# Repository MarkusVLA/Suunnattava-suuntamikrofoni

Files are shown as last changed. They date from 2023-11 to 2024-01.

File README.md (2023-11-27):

# Suunnattava suuntamikrofoni 

Suunnattava suuntamikrofoni on laite, jolla voidaan elektronisesti ohjata äänityksen suuntaa käännettävän suuntauksen avulla. Laite koostuu kahdesta piirikortista: Ensimmäinen piirikortti sisältää kuuden mikrofonin ryhmän, josta luetaan dataa. Toinen piirikortti hoitaa signaalinkäsittelyn ja laitteen ohjauksen ESP32-S3-mikro-ohjaimeen perustuvalla järjestelmällä.

## Mikrofonipiiri

-   ...

## Signaalinkäsittelypiiri

<p float="left">
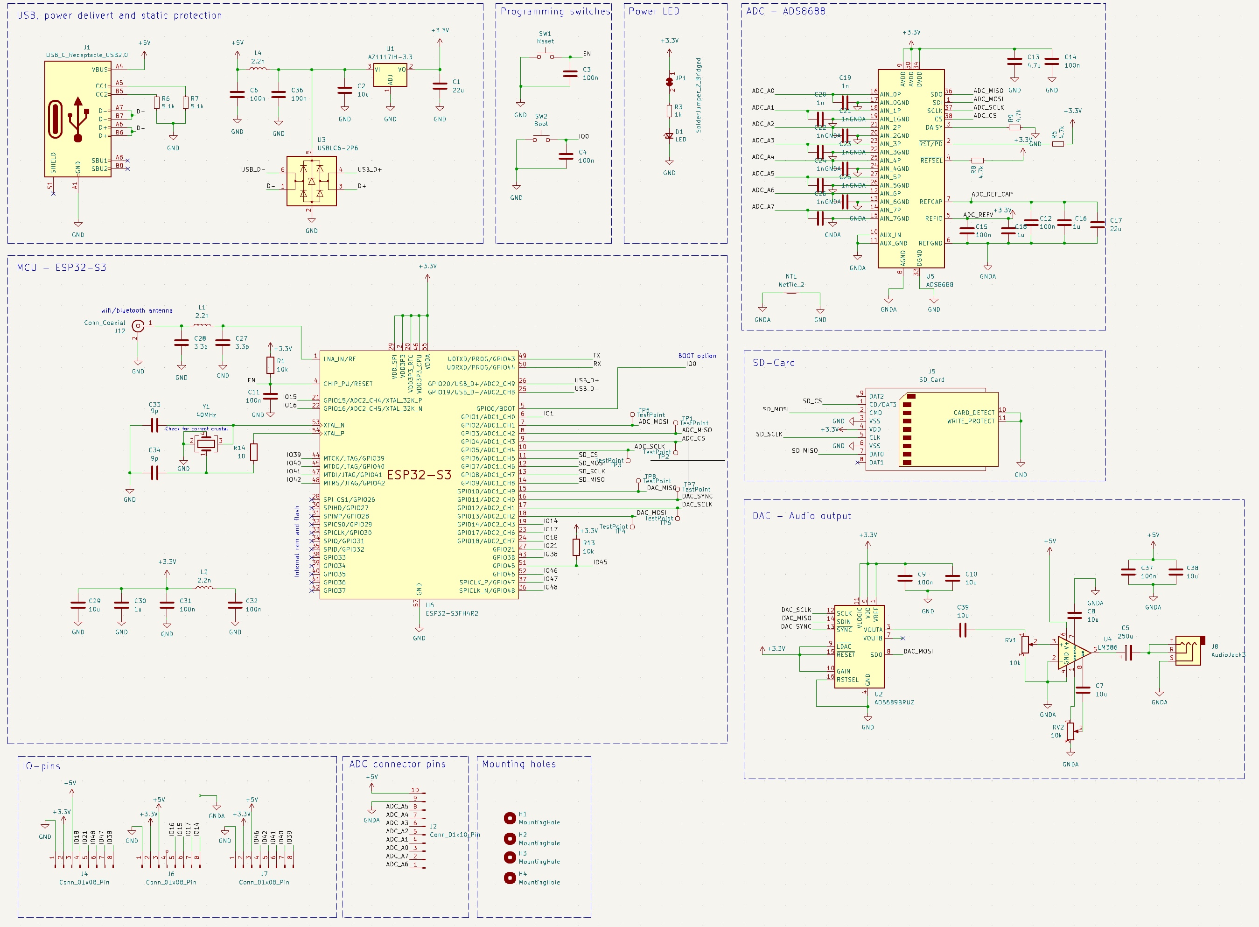
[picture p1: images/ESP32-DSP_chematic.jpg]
  
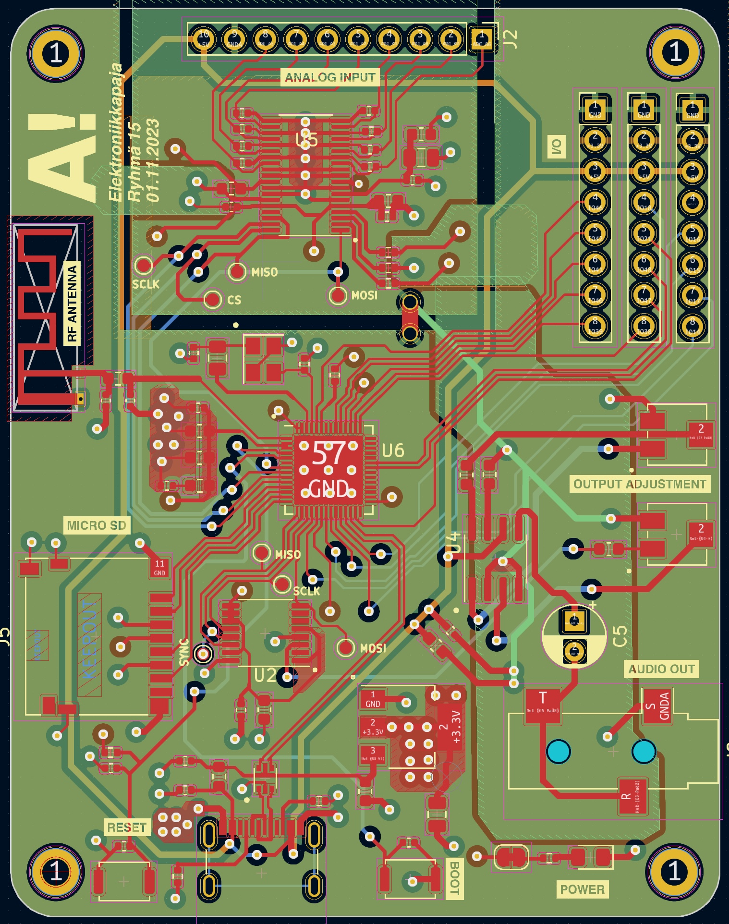
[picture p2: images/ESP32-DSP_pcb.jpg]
  
  <p>Kuva 1: ESP32-DSP piirikaavio ja piirikortti</p>
</p>

<p float="left">
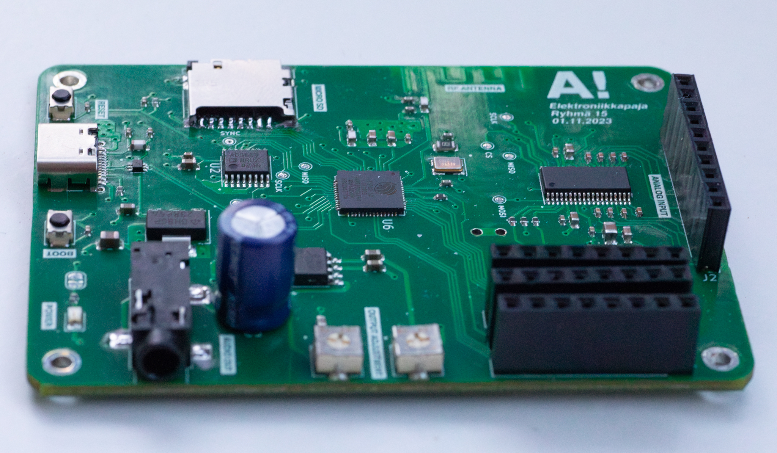
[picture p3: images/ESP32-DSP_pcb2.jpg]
  
  <p>Kuva 2: ESP32-DSP piirikortti toteutettuna</p>
</p>

## TODO
* [x] DSP alustan suunnittelu
* [x] Mikrofoonipiirin suunnittelu
* [x] Piirikorttien kasaus
* [x] Datan keräys ADS8688-ADC:n avulla
* [ ] Beam forming algoritmi
* [ ] Äänen toisto käyttäjälle

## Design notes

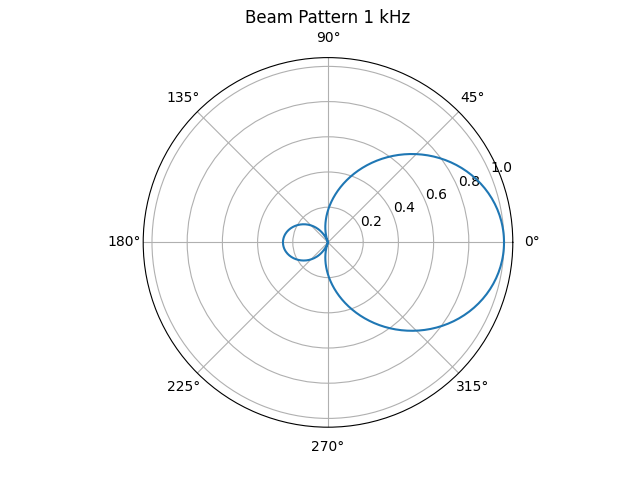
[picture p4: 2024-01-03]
images/Beam_pattern_1kHz.png

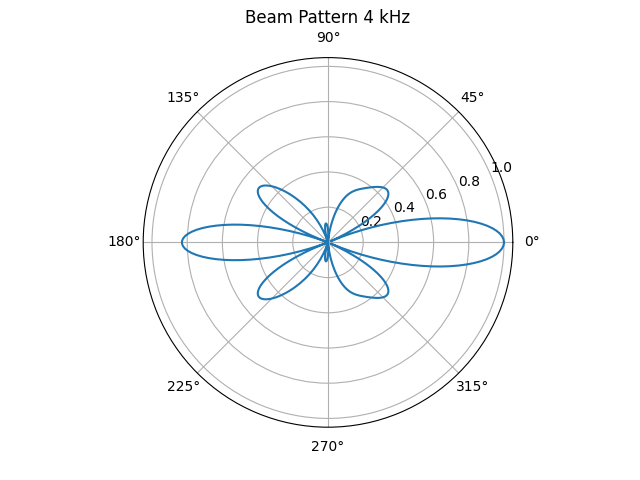
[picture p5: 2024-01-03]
images/Beam_pattern_4kHz.png

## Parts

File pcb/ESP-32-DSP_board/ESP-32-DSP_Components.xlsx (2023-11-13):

Designator | Footprint | Quantity | Value | Component cost [€] | Order link
C10, C2, C29, C38, C39, C7, C8 | 603 | 7 | 10u | 0.12 € | https://www.digikey.fi/fi/products/detail/murata-electronics/GRM188R61A106ME69D/5027560
C11, C12, C14, C15, C3, C31, C32, C36, C4, C6, C37, C9 | 402 | 12 | 100n | 0.09 € | https://www.digikey.fi/fi/products/detail/samsung-electro-mechanics/CL05A104KA5NNNC/3886701
C13 | 603 | 1 | 4.7u | 0.09 € | https://www.digikey.fi/fi/products/detail/samsung-electro-mechanics/CL10A475KP8NNNC/3886702
C16, C18, C30 | 603 | 3 | 1u | 0.09 € | https://www.digikey.fi/fi/products/detail/samsung-electro-mechanics/CL10A105KA8NNNC/3886760
C17 | 805 | 2 | 22u | 0.12 € | https://www.digikey.fi/fi/products/detail/kemet/C0805C224K5RAC7800/754753
C19, C20, C21, C22, C23, C24, C25, C26 | 402 | 8 | 1n | 0.18 € | https://www.digikey.fi/fi/products/detail/tdk-corporation/C1005C0G1H102J050BE/11697944
C27, C28 | 402 | 2 | 3.3p | 0.24 € | https://www.digikey.fi/fi/products/detail/johanson-technology-inc/QSCF500Q3R3B1GV001T/1561531
C33, C34 | 402 | 2 | 20p (crystal load capacitance) | 0.14 € | https://www.digikey.fi/fi/products/detail/murata-electronics/GJM1555C1H200FB01D/2592908
D1 | 805 | 1 | LED | 0.24 € | https://www.digikey.fi/fi/products/detail/liteon/LTST-C171GKT/386793
J1 | USB_C_Receptacle_G-Switch_GT-USB-7010ASV | 1 | USB_C_Receptacle_USB2.0 | 0.94 € | https://www.digikey.fi/fi/products/detail/amphenol-cs-commercial-products/12402012E212A/13683192
J5 | microSD_HC_Hirose_DM3D-SF | 1 | SD_Card | 1.66 € | https://www.digikey.fi/fi/products/detail/hirose-electric-co-ltd/DM3D-SF/1786510
J8 | Jack_3.5mm_Switronic_ST-005-G_horizontal | 1 | AudioJack3 | 1.50 € | https://www.digikey.fi/fi/products/detail/kycon-inc/STX-3500-3NTR/9975996
L1, L2, L4 | 603 | 3 | 2.2n | 0.09 € | https://www.digikey.fi/fi/products/detail/johanson-technology-inc/LRC0603CS2N2GV001T/1561288
R1, R13 | 402 | 2 | 10k | 0.09 € | https://www.digikey.fi/fi/products/detail/bourns-inc/CR0402-FX-1002GLF/3593192
R14 | 805 | 1 | 10 | 0.10 € | https://www.digikey.fi/fi/products/detail/panasonic-electronic-components/ERJ-6ENF10R0V/110893
R3 | 402 | 1 | 1k | 0.09 € | https://www.digikey.fi/fi/products/detail/yageo/RC0402FR-071KL/726513
R5, R8, R9 | 402 | 3 | 4.7k | 0.09 € | https://www.digikey.fi/fi/products/detail/yageo/RC0402FR-074K7L/2827563
R6, R7 | 402 | 2 | 5.1k | 0.09 € | https://www.digikey.fi/fi/products/detail/yageo/RC0402FR-135K1L/14286364
RV1, RV2 | Potentiometer_Bourns_3214J_Horizontal | 2 | 10k | 1.73 € | https://www.digikey.fi/fi/products/detail/bourns-inc/3314J-1-103E/86580
SW1 | SW_Push_SPST_NO_Alps_SKRK | 1 | Reset | 0.72 € | https://www.digikey.fi/fi/products/detail/alps-alpine/SKRKAHE020/19529210
SW2 | SW_Push_SPST_NO_Alps_SKRK | 1 | Boot | 0.72 € | https://www.digikey.fi/fi/products/detail/alps-alpine/SKRKAHE020/19529210
U1 | SOT-223-3_TabPin2 | 1 | AZ1117IH-3.3 | 0.36 € | https://www.digikey.fi/fi/products/detail/diodes-incorporated/AZ1117IH-3-3TRG1/5699672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
U2 | TSSOP-16_4.4x5mm_P0.65mm | 1 | AD5689BRUZ | 10.66 € | https://www.digikey.fi/fi/products/detail/analog-devices-inc/AD5689BRUZ/3925735
U3 | SOT-666 | 1 | USBLC6-2P6 | 0.59 € | https://www.digikey.fi/fi/products/detail/stmicroelectronics/USBLC6-2P6/1007440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
U4 | SOIC-8_3.9x4.9mm_P1.27mm | 1 | LM386 | 1.05 € | https://www.digikey.fi/fi/products/detail/texas-instruments/LM386MX-1-NOPB/212680
U5 | TSSOP-38_4.4x9.7mm_P0.5mm | 1 | ADS8688 | 19.29 € | https://www.digikey.fi/fi/products/detail/texas-instruments/ADS8688AIDBT/5417855
U6 | QFN-56-1EP_7x7mm_P0.4mm_EP5.6x5.6mm | 1 | ESP32-S3FH4R2 | 2.16 € | https://www.mouser.fi/ProductDetail/Espressif-Systems/ESP32-S3FH4R2?qs=tlsG%2FOw5FFjPrwkmZSBQNA%3D%3D
Y1 | Crystal_SMD_3225-4Pin_3.2x2.5mm | 1 | 40MHz | 0.40 € | https://www.digikey.fi/fi/products/detail/ecs-inc/ECS-400-18-33-JGN-TR3/14825140
Board cost [€]:
49.56

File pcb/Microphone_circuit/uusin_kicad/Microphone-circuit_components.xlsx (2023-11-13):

Designator | Footprint | Quantity | Value | Component cost [€] | Order link
C1, C11, C16, C21, C26, C6 | 805 | 8 | 0.1u | 0.09 € | https://www.digikey.fi/fi/products/detail/kemet/C0805C104M5RAC7800/411168
C10, C15, C2, C20, C25, C30 | CP_Radial_D7.5mm_P2.50mm |  | 100u | 0.00 € | Pajalta
C12, C13, C17, C18, C22, C23, C27, C28, C3, C4, C7, C8 | 805 | 14 | 10u | 0.15 € | https://www.digikey.fi/fi/products/detail/murata-electronics/GRM21BR61C106KE15K/2546903
C14, C19, C24, C29, C5, C9 | 805 | 8 | 0.047u | 0.13 € | https://www.digikey.fi/fi/products/detail/kemet/C0805C473K5RAC7800/411165
C31, C32, C33, C34, C35, C36 | 805 | 8 | 5n | 0.24 € | https://www.digikey.fi/fi/products/detail/kyocera-avx/08055C502KAT2A/1603019
MK1, MK2, MK3, MK4, MK5, MK6 | Mikrophoni1 | 8 | Microphone_Condenser | 1.11 € | https://www.digikey.fi/fi/products/detail/ole-wolff-electronics-inc/OWMO-9745TA-32-CC101/20371554
R1, R10, R13, R16, R4, R7 | 805 | 8 | 10k | 0.09 € | https://www.digikey.fi/fi/products/detail/stackpole-electronics-inc/RMCF0805JT10K0/1757762
R11, R14, R17, R2, R5, R8 | 805 | 8 | 3k | 0.09 € | https://www.digikey.fi/fi/products/detail/stackpole-electronics-inc/RMCF0805JT3K00/1757864
R12, R15, R18, R3, R6, R9 | 805 | 8 | 10 | 0.10 € | https://www.digikey.fi/fi/products/detail/panasonic-electronic-components/ERJ-6ENF10R0V/110893
U1, U2, U3, U4, U5, U6 | DIP-8_W7.62mm | 8 | LM386 | 1.21 € | https://www.digikey.fi/fi/products/detail/texas-instruments/LM386N-1-NOPB/6284
Board cost [€]
26.58

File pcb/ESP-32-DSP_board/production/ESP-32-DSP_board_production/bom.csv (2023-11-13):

Designator | Footprint | Quantity | Value
C1, C17 | 0805 | 2 | 22u
C10, C2, C29, C38, C39, C7, C8 | 0603 | 7 | 10u
C11, C12, C14, C15, C3, C31, C32, C36, C37, C4, C6, C9 | 0402 | 12 | 100n
C13 | 0603 | 1 | 4.7u
C16, C18, C30 | 0603 | 3 | 1u
C19, C20, C21, C22, C23, C24, C25, C26 | 0402 | 8 | 1n
C27, C28 | 0402 | 2 | 3.3p
C33, C34 | 0402 | 2 | 12p
C5 | CP_Radial_D5.0mm_P2.50mm | 1 | 250u
D1 | 0805 | 1 | LED
J1 | USB_C_Receptacle_G-Switch_GT-USB-7010ASV | 1 | USB_C_Receptacle_USB2.0
J5 | microSD_HC_Hirose_DM3D-SF | 1 | SD_Card
J8 | Jack_3.5mm_CUI_SJ-3523-SMT_Horizontal | 1 | AudioJack3
JP1 | SolderJumper-2_P1.3mm_Bridged_RoundedPad1.0x1.5mm | 1 | SolderJumper_2_Bridged
L1, L2, L4 | 0603 | 3 | 2.2n
R1, R13 | 0402 | 2 | 10k
R14 | 0805 | 1 | 10
R3 | 0402 | 1 | 1k
R5, R8, R9 | 0402 | 3 | 4.7k
R6, R7 | 0402 | 2 | 5.1k
RV1, RV2 | Potentiometer_Bourns_3214J_Horizontal | 2 | 10k
SW1 | SW_Push_SPST_NO_Alps_SKRK | 1 | Reset
SW2 | SW_Push_SPST_NO_Alps_SKRK | 1 | Boot
TP1, TP2, TP3, TP4, TP5, TP6, TP7, TP8 | TestPoint_Pad_D1.0mm | 8 | TestPoint
U1 | SOT-223-3_TabPin2 | 1 | AZ1117IH-3.3
U2 | TSSOP-16_4.4x5mm_P0.65mm | 1 | AD5689BRUZ
U3 | SOT-666 | 1 | USBLC6-2P6
U4 | SOIC-8_3.9x4.9mm_P1.27mm | 1 | LM386
U5 | TSSOP-38_4.4x9.7mm_P0.5mm | 1 | ADS8688
U6 | QFN-56-1EP_7x7mm_P0.4mm_EP5.6x5.6mm | 1 | ESP32-S3FH4R2
Y1 | Crystal_SMD_3225-4Pin_3.2x2.5mm | 1 | 40MHz

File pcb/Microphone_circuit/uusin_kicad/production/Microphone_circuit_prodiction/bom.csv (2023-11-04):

Designator | Footprint | Quantity | Value | LCSC Part #
C1, C11, C16, C21, C26, C6 | 0805 | 6 | 0.1u
C10, C15, C2, C20, C25, C30 | CP_Radial_D7.5mm_P2.50mm | 6 | 100u
C12, C13, C17, C18, C22, C23, C27, C28, C3, C4, C7, C8 | 0805 | 12 | 10u
C14, C19, C24, C29, C5, C9 | 0805 | 6 | 0.047u
C31, C32, C33, C34, C35, C36 | 0805 | 6 | 5n
J1 | PinSocket_1x10_P2.54mm_Vertical | 1 | Conn_01x10_Pin
MK1, MK2, MK3, MK4, MK5, MK6 | Mikrophoni1 | 6 | Microphone_Condenser
R1, R10, R13, R16, R4, R7 | 0805 | 6 | 10k
R11, R14, R17, R2, R5, R8 | 0805 | 6 | 3k
R12, R15, R18, R3, R6, R9 | 0805 | 6 | 10
U1, U2, U3, U4, U5, U6 | DIP-8_W7.62mm | 6 | LM386

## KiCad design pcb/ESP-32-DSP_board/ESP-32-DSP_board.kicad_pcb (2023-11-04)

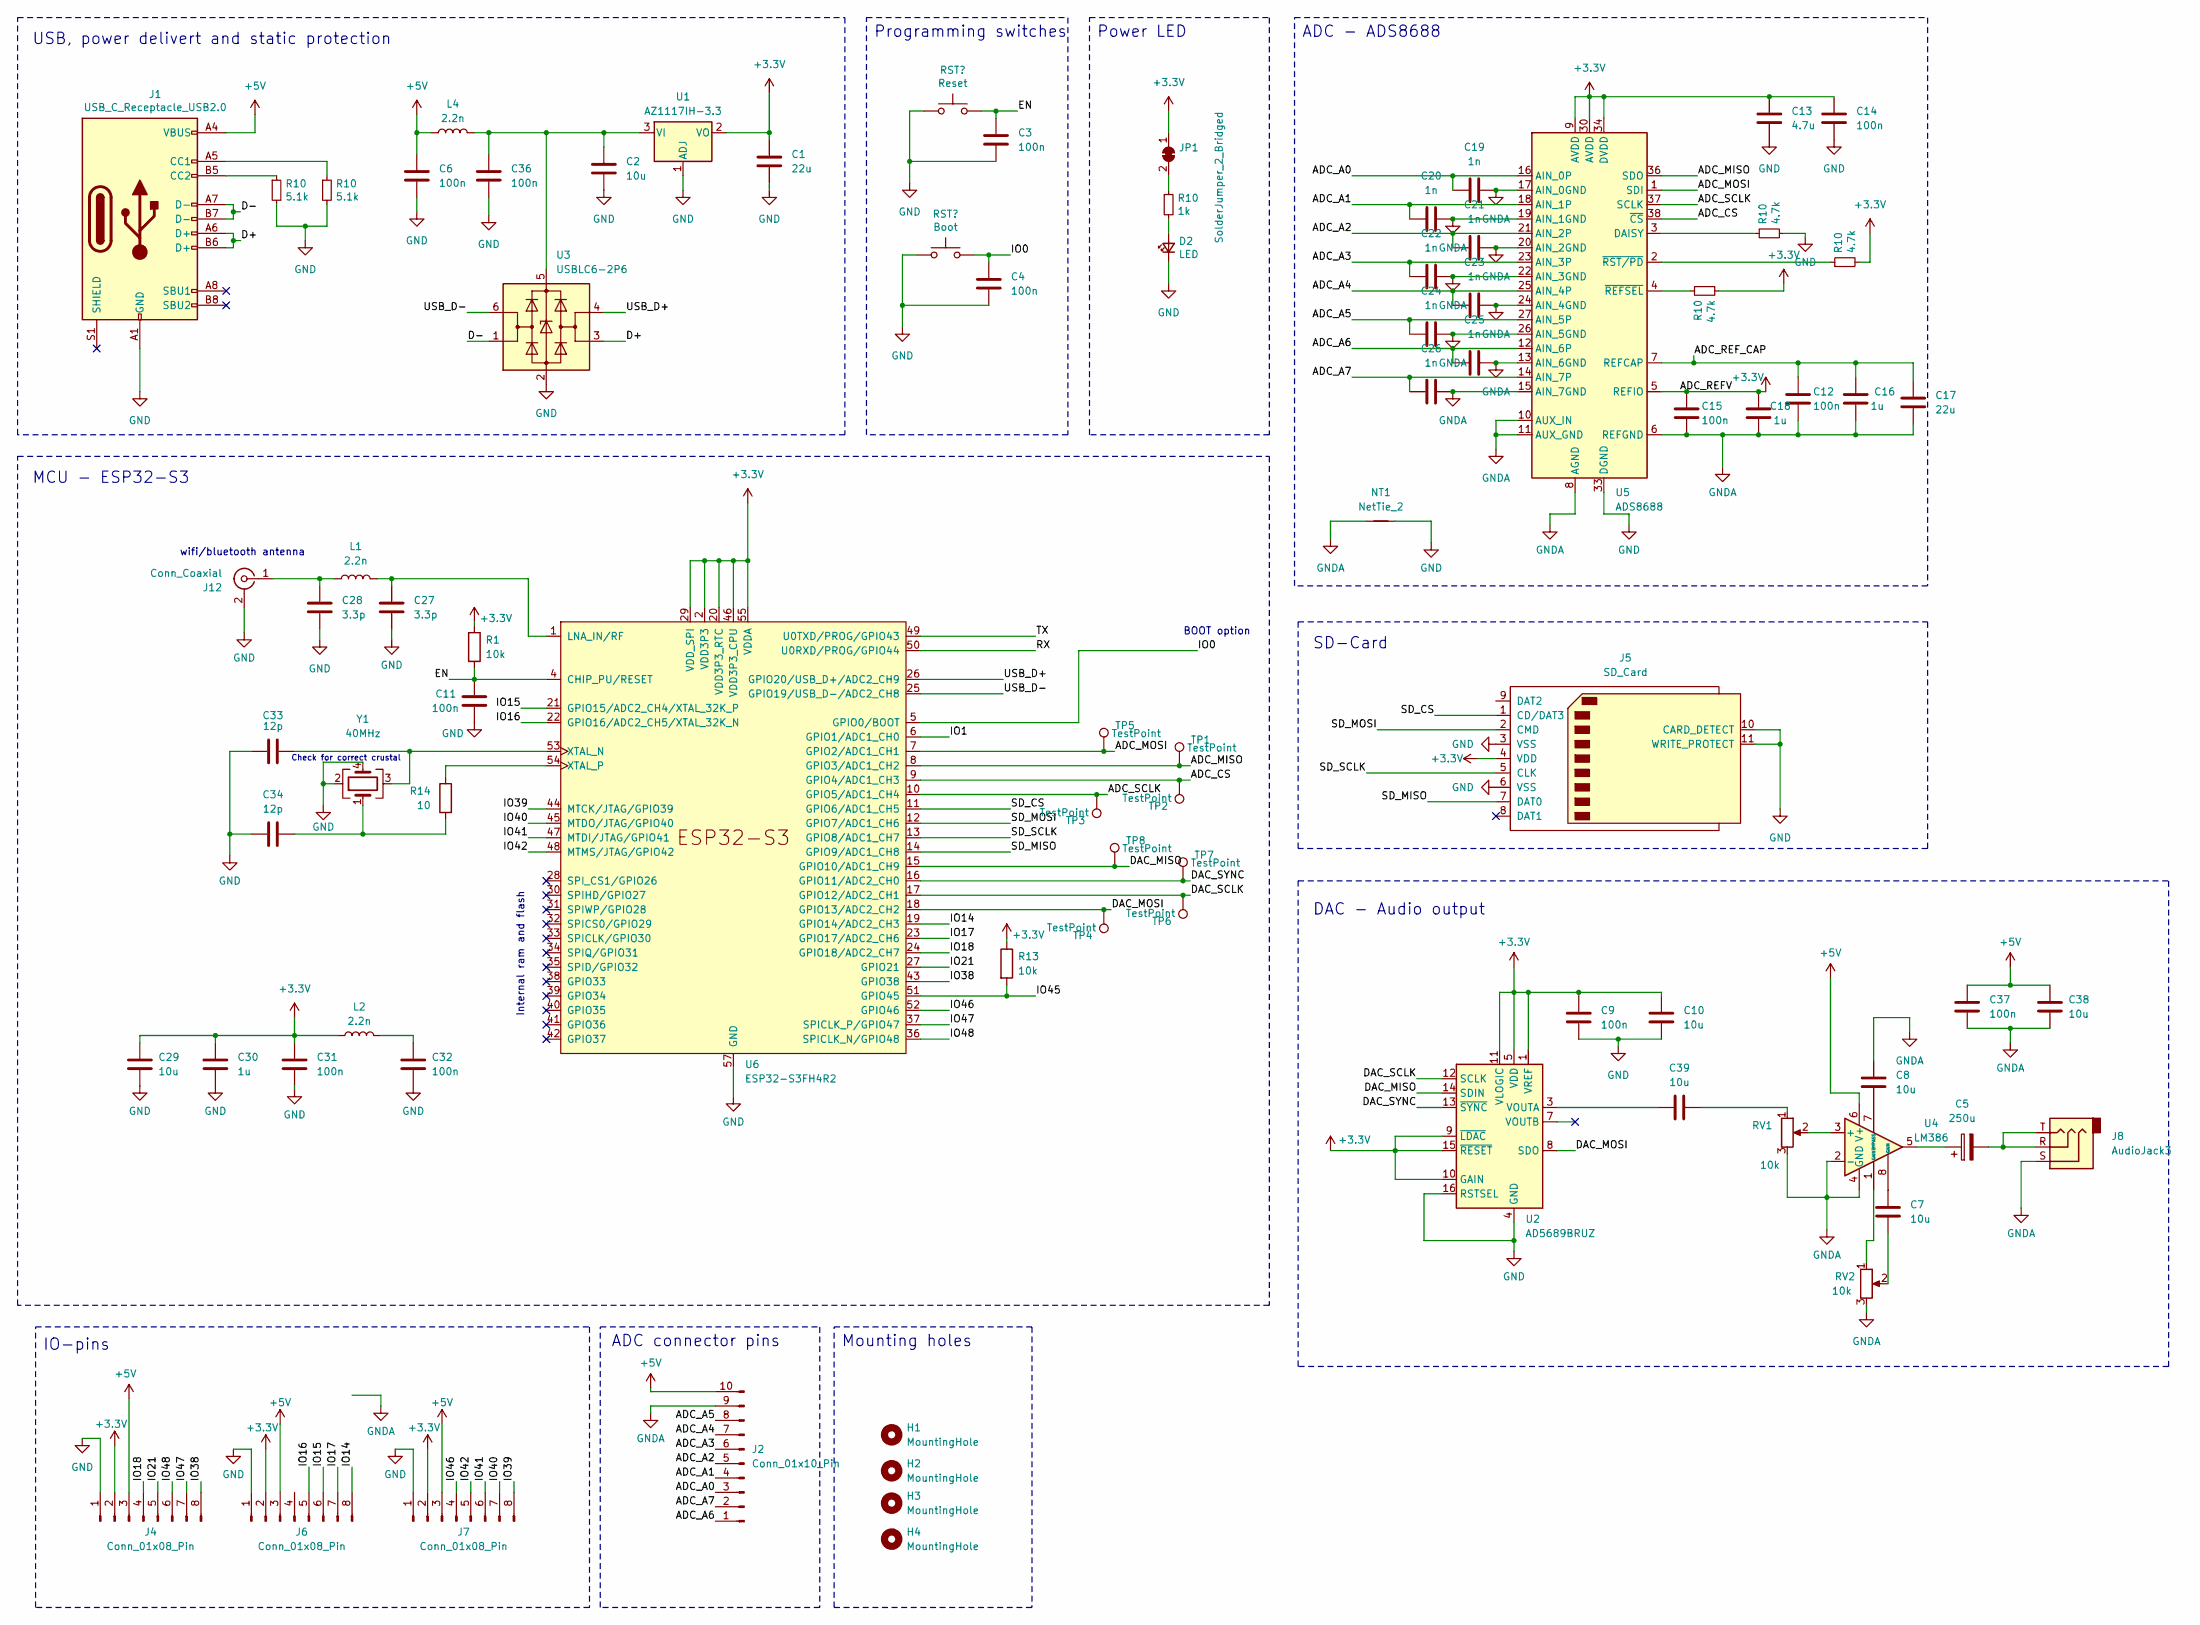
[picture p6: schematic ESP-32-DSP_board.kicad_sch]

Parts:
C1, C17: 22u; C_0805_2012Metric
C2, C7, C8, C10, C29, C38, C39: 10u; C_0603_1608Metric
C3, C4, C6, C9, C11, C12, C14, C15, C31, C32, C36, C37: 100n; C_0402_1005Metric
C5: 250u; CP_Radial_D5.0mm_P2.50mm
C13: 4.7u; C_0603_1608Metric
C16, C18, C30: 1u; C_0603_1608Metric
C19, C20, C21, C22, C23, C24, C25, C26: 1n; C_0402_1005Metric
C27, C28: 3.3p; C_0402_1005Metric
C33, C34: 12p; C_0402_1005Metric
D2: LED; LED_0805_2012Metric_Pad1.15x1.40mm_HandSolder; LCSC C205445
H1, H2, H3, H4: MountingHole; MountingHole_2.2mm_M2_DIN965_Pad
J1: USB_C_Receptacle_USB2.0; USB_C_Receptacle_G-Switch_GT-USB-7010ASV
J2: Conn_01x10_Pin; PinHeader_1x10_P2.54mm_Vertical
J4, J6, J7: Conn_01x08_Pin; PinHeader_1x08_P2.54mm_Vertical
J5: SD_Card; microSD_HC_Hirose_DM3D-SF
J8: AudioJack3; Jack_3.5mm_CUI_SJ-3523-SMT_Horizontal
J12: Conn_Coaxial; Texas_SWRA117D_2.4GHz_Right
JP1: SolderJumper_2_Bridged; SolderJumper-2_P1.3mm_Bridged_RoundedPad1.0x1.5mm
L1, L2, L4: 2.2n; L_0603_1608Metric
NT1: NetTie_2; NetTie-2_THT_Pad1.0mm
R1, R13: 10k; R_0402_1005Metric
R10: 4.7k; R_0402_1005Metric; LCSC C163928
R14: 10; R_0805_2012Metric
RV1, RV2: 10k; Potentiometer_Bourns_3214J_Horizontal
SW1: Reset; SW_Push_SPST_NO_Alps_SKRK; LCSC C115357
TP1, TP2, TP3, TP4, TP5, TP6, TP7, TP8: TestPoint; TestPoint_Pad_D1.0mm
U1: AZ1117IH-3.3; SOT-223-3_TabPin2
U2: AD5689BRUZ; TSSOP-16_4.4x5mm_P0.65mm
U3: USBLC6-2P6; SOT-666
U4: LM386; SOIC-8_3.9x4.9mm_P1.27mm
U5: ADS8688; TSSOP-38_4.4x9.7mm_P0.5mm; JLCPCB Rotation Offset -90
U6: ESP32-S3FH4R2; QFN-56-1EP_7x7mm_P0.4mm_EP5.6x5.6mm
Y1: 40MHz; Crystal_SMD_3225-4Pin_3.2x2.5mm

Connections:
+3.3V: C1.1, C9.1, C10.1, C13.1, C14.1, C15.2, C18.1, C29.1, C30.1, C31.1, J4.2, J5.4 (VDD), J6.2, J7.2, JP1.1 (A), L2.1, R1.1, R13.1, U1.2 (VO), U2.1 (VREF), U2.5 (VDD), U2.9 (~LDAC), U2.10 (GAIN), U2.11 (VLOGIC), U2.15 (~RESET), U5.5 (REFIO), U5.9 (AVDD), U5.30 (AVDD), U5.34 (DVDD), U6.2 (VDD3P3), U6.3 (VDD3P3), U6.20 (VDD3P3_RTC), U6.29 (VDD_SPI), U6.46 (VDD3P3_CPU), U6.55 (VDDA), U6.56 (VDDA); also elsewhere on the board
+5V: C6.1, C37.1, C38.1, J1.A4 (VBUS), J1.A9 (VBUS), J1.B4 (VBUS), J1.B9 (VBUS), J2.10, J4.3, J6.3, J7.3, L4.1, U4.6 (V+)
/ADC_A0: C19.1, J2.3, U5.16 (AIN_0P)
/ADC_A1: C20.1, J2.4, U5.18 (AIN_1P)
/ADC_A2: C21.2, J2.5, U5.21 (AIN_2P)
/ADC_A3: C22.2, J2.6, U5.23 (AIN_3P)
/ADC_A4: C23.2, J2.7, U5.25 (AIN_4P)
/ADC_A5: C24.2, J2.8, U5.27 (AIN_5P)
/ADC_A6: C25.1, J2.1, U5.12 (AIN_6P)
/ADC_A7: C26.2, J2.2, U5.14 (AIN_7P)
/ADC_CS: TP2.1, U5.38 (~CS), U6.9 (GPIO4/ADC1_CH3)
/ADC_MISO: TP1.1, U5.36 (SDO), U6.8 (GPIO3/ADC1_CH2)
/ADC_MOSI: TP5.1, U5.1 (SDI), U6.7 (GPIO2/ADC1_CH1)
/ADC_REF_CAP: C12.2, C16.1, C17.1, U5.7 (REFCAP)
/ADC_SCLK: TP3.1, U5.37 (SCLK), U6.10 (GPIO5/ADC1_CH4)
/D+: J1.A6 (D+), J1.B6 (D+), U3.3 (I/O2)
/D-: J1.A7 (D-), J1.B7 (D-), U3.1 (I/O1)
/DAC_MISO: TP8.1, U2.14 (SDIN), U6.15 (GPIO10/ADC1_CH9)
/DAC_MOSI: TP4.1, U2.8 (SDO), U6.18 (GPIO13/ADC2_CH2)
/DAC_SCLK: TP6.1, U2.12 (SCLK), U6.17 (GPIO12/ADC2_CH1)
/DAC_SYNC: TP7.1, U2.13 (~SYNC), U6.16 (GPIO11/ADC2_CH0)
/IO1: U6.6 (GPIO1/ADC1_CH0)
/IO14: J6.8, U6.19 (GPIO14/ADC2_CH3)
/IO15: J6.6, U6.21 (GPIO15/ADC2_CH4/XTAL_32K_P)
/IO16: J6.5, U6.22 (GPIO16/ADC2_CH5/XTAL_32K_N)
/IO17: J6.7, U6.23 (GPIO17/ADC2_CH6)
/IO18: J4.4, U6.24 (GPIO18/ADC2_CH7)
/IO21: J4.5, U6.27 (GPIO21)
/IO38: J4.8, U6.43 (GPIO38)
/IO39: J7.8, U6.44 (MTCK/JTAG/GPIO39)
/IO40: J7.7, U6.45 (MTDO/JTAG/GPIO40)
/IO41: J7.6, U6.47 (MTDI/JTAG/GPIO41)
/IO42: J7.5, U6.48 (MTMS/JTAG/GPIO42)
/IO45: R13.2, U6.51 (GPIO45)
/IO46: J7.4, U6.52 (GPIO46)
/IO47: J4.7, U6.37 (SPICLK_P/GPIO47)
/IO48: J4.6, U6.36 (SPICLK_N/GPIO48)
/RX: U6.50 (U0RXD/PROG/GPIO44)
/SD_CS: J5.1 (CD/DAT3), U6.11 (GPIO6/ADC1_CH5)
/SD_MISO: J5.7 (DAT0), U6.14 (GPIO9/ADC1_CH8)
/SD_MOSI: J5.2 (CMD), U6.12 (GPIO7/ADC1_CH6)
/SD_SCLK: J5.5 (CLK), U6.13 (GPIO8/ADC1_CH7)
/TX: U6.49 (U0TXD/PROG/GPIO43)
/USB_D+: U3.4 (I/O2), U6.26 (GPIO20/USB_D+/ADC2_CH9)
/USB_D-: U3.6 (I/O1), U6.25 (GPIO19/USB_D-/ADC2_CH8)
GND: C1.2, C2.2, C3.2, C4.2, C6.2, C9.2, C10.2, C11.2, C13.2, C14.2, C27.2, C28.2, C29.2, C30.2, C31.2, C32.2, C33.1, C34.1, C36.2, J1.A1 (GND), J1.A12 (GND), J1.B1 (GND), J1.B12 (GND), J4.1, J5.3 (VSS), J5.6 (VSS), J5.10 (CARD_DETECT), J5.11 (WRITE_PROTECT), J6.1, J7.1, J12.2 (Ext), NT1.2, SW1.2, U1.1 (ADJ), U2.4 (GND), U2.16 (RSTSEL), U3.2 (GND), U5.33 (DGND), U6.57 (GND), Y1.2, Y1.4; also elsewhere on the board
GNDA: C8.1, C12.1, C15.1, C16.2, C17.2, C18.2, C19.2, C20.2, C21.1, C22.1, C23.1, C24.1, C25.2, C26.1, C37.2, C38.2, J2.9, J8.S, NT1.1, RV1.3, RV2.3, U4.2 (-), U4.4 (GND), U5.6 (REFGND), U5.8 (AGND), U5.10 (AUX_IN), U5.11 (AUX_GND), U5.13 (AIN_6GND), U5.15 (AIN_7GND), U5.17 (AIN_0GND), U5.19 (AIN_1GND), U5.20 (AIN_2GND), U5.22 (AIN_3GND), U5.24 (AIN_4GND), U5.26 (AIN_5GND), U5.28 (AGND), U5.29 (AGND), U5.31 (AGND), U5.32 (AGND)
unnamed: C5.1, U4.5
unnamed: C5.2, J8.R, J8.T
unnamed: C7.1, U4.8 (GAIN)
unnamed: C7.2, RV2.2
unnamed: C32.1, L2.2
unnamed: C34.2, R14.2, Y1.1
unnamed: C39.2, RV1.1
unnamed 55: J1.A5 (CC1); also elsewhere on the board
unnamed 56: J1.B5 (CC2); also elsewhere on the board
unnamed: C28.1, J12.1 (In), L1.1
unnamed 58: JP1.2 (B); also elsewhere on the board
unnamed: RV2.1, U4.1 (GAIN)
unnamed: C2.1, C36.1, L4.2, U1.3 (VI), U3.5 (VBUS)
unnamed: C39.1, U2.3 (VOUTA)
unnamed: RV1.2, U4.3 (+)
unnamed: C8.2, U4.7 (BYPASS)
unnamed 64: U5.3 (DAISY); also elsewhere on the board
unnamed 65: U5.4 (~REFSEL); also elsewhere on the board
unnamed 66: U5.2 (~RST/PD); also elsewhere on the board
unnamed: C27.1, L1.2, U6.1 (LNA_IN/RF)
unnamed: C33.2, U6.53 (XTAL_N), Y1.3
unnamed: R14.1, U6.54 (XTAL_P)

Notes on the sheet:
MCU - ESP32-S3
wifi/bluetooth antenna
USB, power delivert and static protection
Power LED
IO-pins
Internal ram and flash
ADC connector pins
BOOT option
Check for correct crustal
DAC - Audio output
ADC - ADS8688
Programming switches
Mounting holes
SD-Card

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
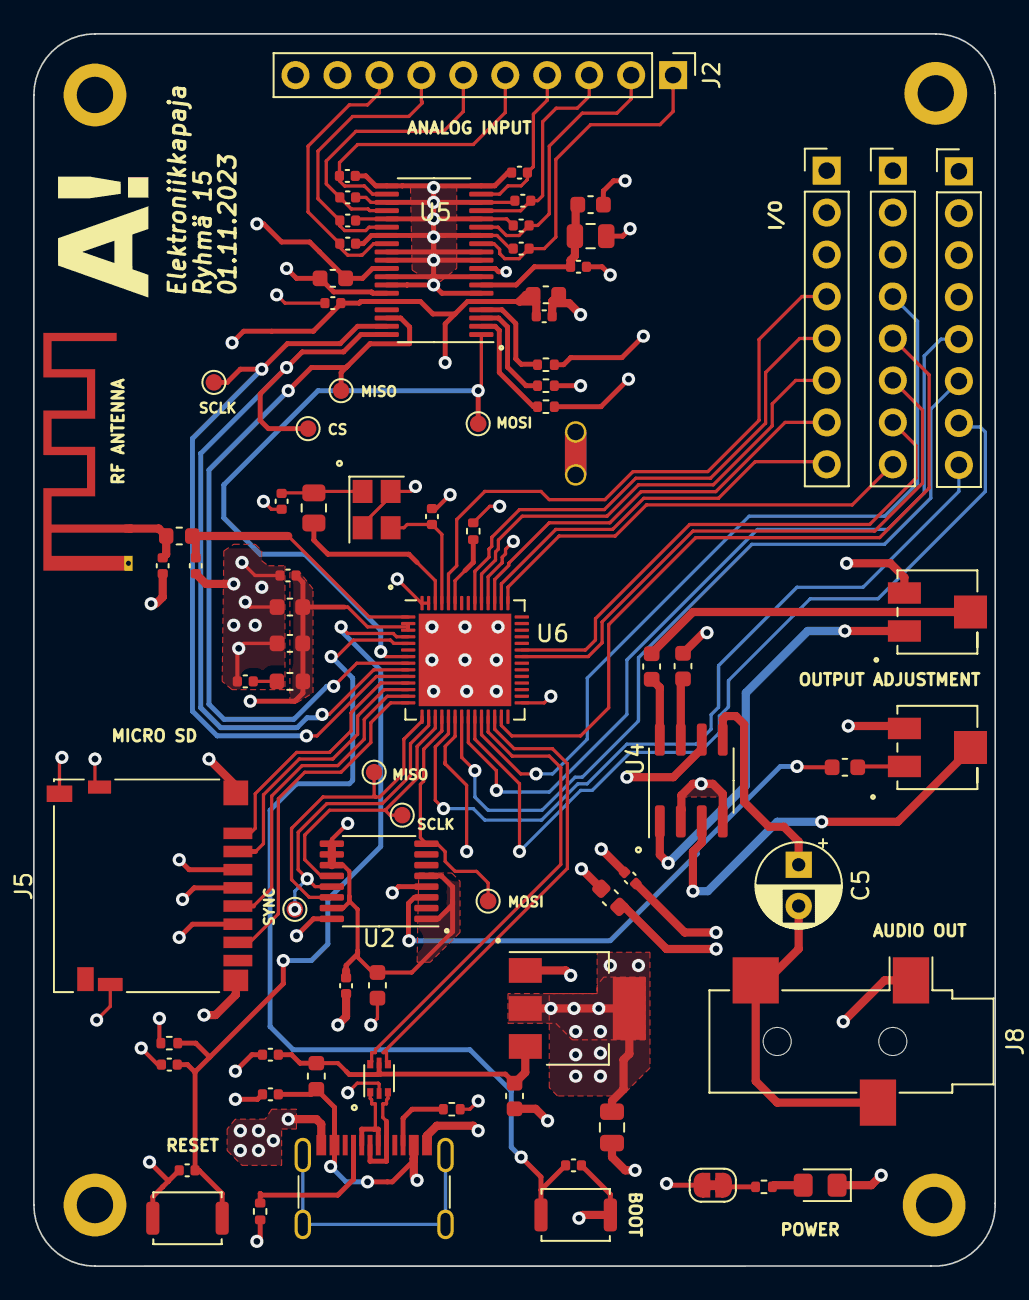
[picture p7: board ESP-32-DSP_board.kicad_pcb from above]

Board: 4 copper layers, 58.2 x 74.6 mm, 84 parts (0 on the bottom side), 69 nets.

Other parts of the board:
D1: LED; LED_0805_2012Metric_Pad1.15x1.40mm_HandSolder
R3: 1k; R_0402_1005Metric
R5, R8, R9: 4.7k; R_0402_1005Metric
R6, R7: 5.1k; R_0402_1005Metric
SW2: Boot; SW_Push_SPST_NO_Alps_SKRK

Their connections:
+3.3V: R5.2, R8.2; also elsewhere on the board
GND: D1.1 (K), R6.2, R7.2, R9.2, SW2.2; also elsewhere on the board
unnamed: D1.2 (A), R3.2
unnamed 55: R7.1; also elsewhere on the board
unnamed 56: R6.1; also elsewhere on the board
unnamed 58: R3.1; also elsewhere on the board
unnamed 64: R9.1; also elsewhere on the board
unnamed 65: R8.1; also elsewhere on the board
unnamed 66: R5.1; also elsewhere on the board

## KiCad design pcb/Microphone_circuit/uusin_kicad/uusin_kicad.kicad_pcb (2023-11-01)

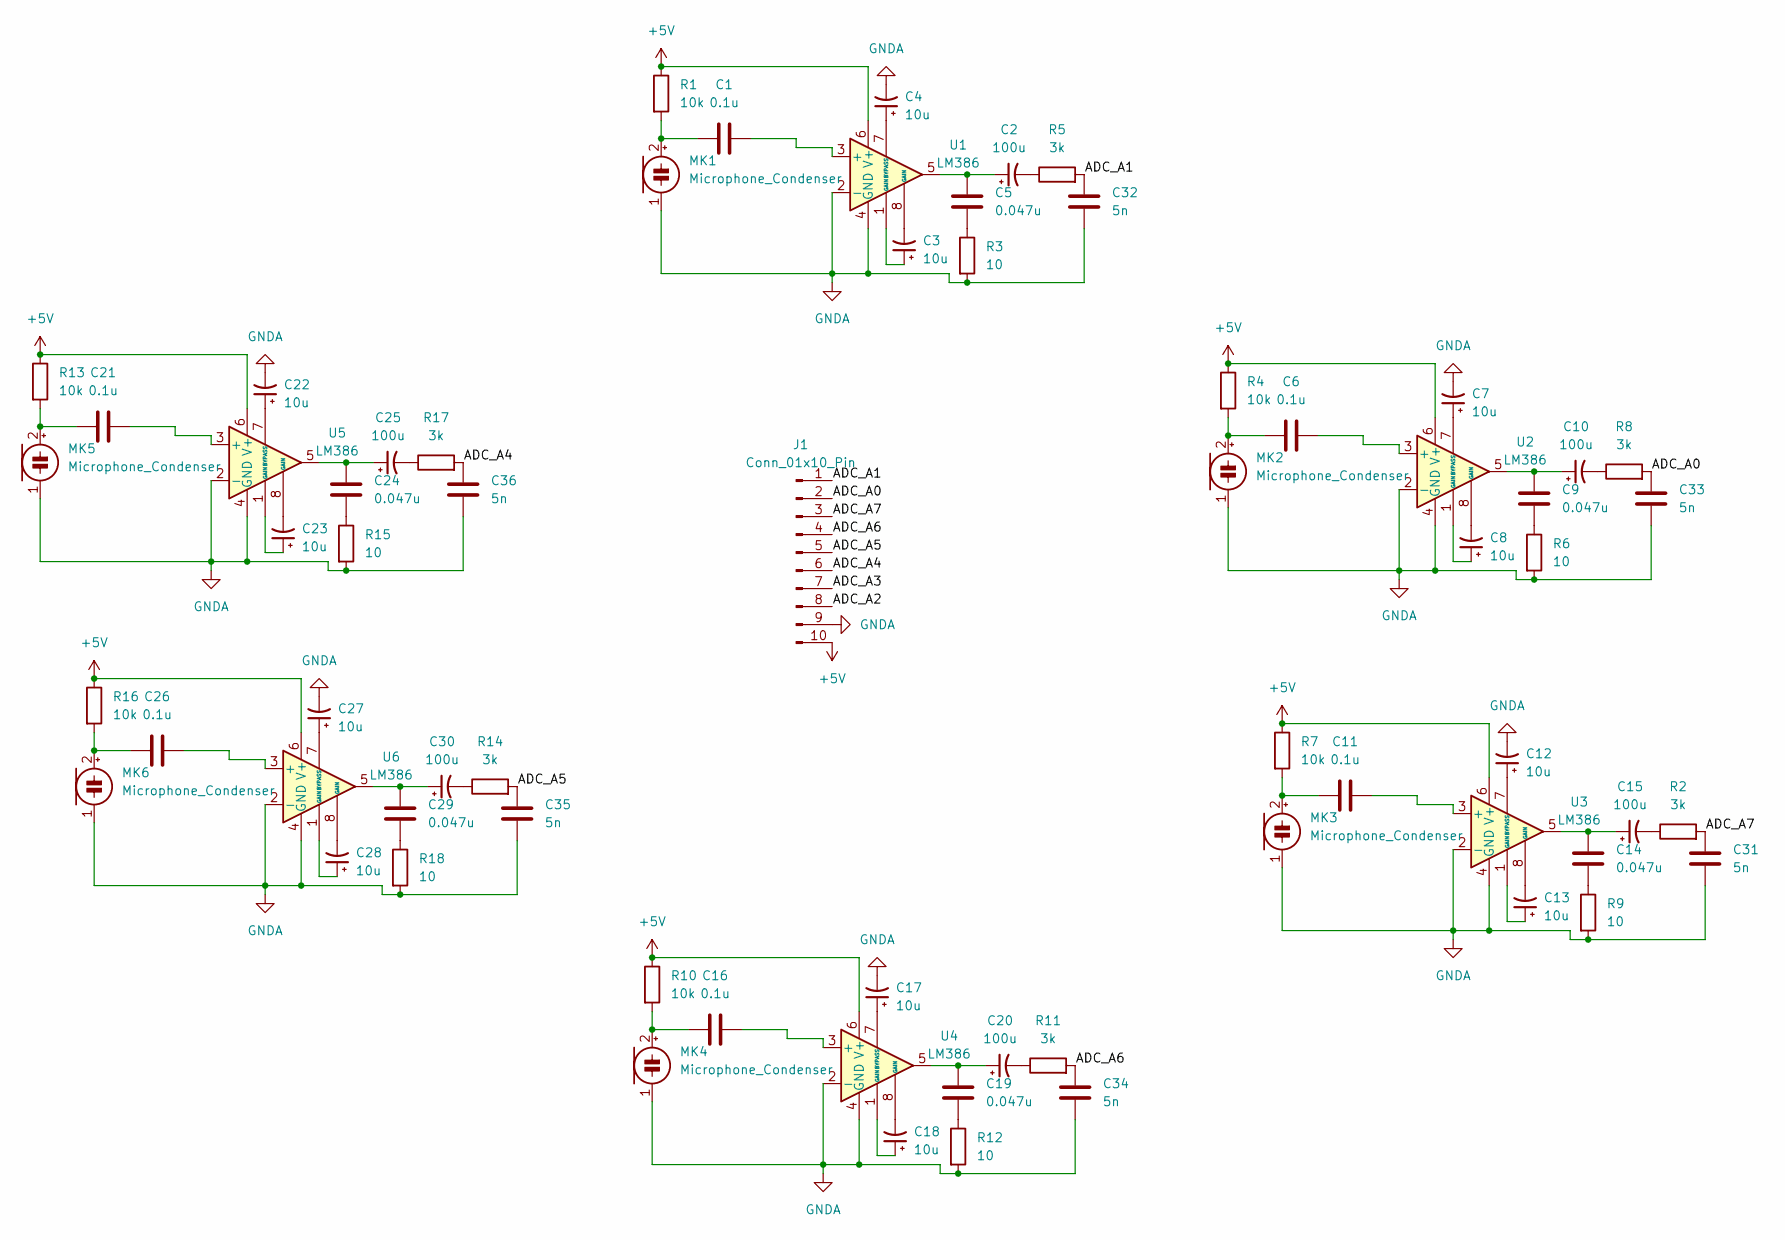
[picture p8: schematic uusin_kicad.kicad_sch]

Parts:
C1, C6, C11, C16, C21, C26: 0.1u; C_0805_2012Metric_Pad1.18x1.45mm_HandSolder
C2, C10, C15, C20, C25, C30: 100u; CP_Radial_D7.5mm_P2.50mm
C3, C4, C7, C8, C12, C13, C17, C18, C22, C23, C27, C28: 10u; C_0805_2012Metric_Pad1.18x1.45mm_HandSolder
C5, C9, C14, C19, C24, C29: 0.047u; C_0805_2012Metric_Pad1.18x1.45mm_HandSolder
C31, C32, C33, C34, C35, C36: 5n; C_0805_2012Metric_Pad1.18x1.45mm_HandSolder
J1: Conn_01x10_Pin; PinSocket_1x10_P2.54mm_Vertical
MK1, MK2, MK3, MK4, MK5, MK6: Microphone_Condenser; Mikrophoni1
R1, R4, R7, R10, R13, R16: 10k; R_0805_2012Metric_Pad1.20x1.40mm_HandSolder
R2, R5, R8, R11, R14, R17: 3k; R_0805_2012Metric_Pad1.20x1.40mm_HandSolder
R3, R6, R9, R12, R15, R18: 10; R_0805_2012Metric_Pad1.20x1.40mm_HandSolder
U1, U2, U3, U4, U5, U6: LM386; DIP-8_W7.62mm

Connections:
+5V: J1.10, R1.1, R4.1, R7.1, R10.1, R13.1, R16.1, U1.6 (V+), U2.6 (V+), U3.6 (V+), U4.6 (V+), U5.6 (V+), U6.6 (V+)
/ADC_A0: C33.1, J1.2, R8.2
/ADC_A1: C32.1, J1.1, R5.2
/ADC_A2: J1.8
/ADC_A3: J1.7
/ADC_A4: C36.1, J1.6, R17.2
/ADC_A5: C35.1, J1.5, R14.2
/ADC_A6: C34.1, J1.4, R11.2
/ADC_A7: C31.1, J1.3, R2.2
GNDA: C4.2, C7.2, C12.2, C17.2, C22.2, C27.2, C31.2, C32.2, C33.2, C34.2, C35.2, C36.2, J1.9, MK1.1 (-), MK2.1 (-), MK3.1 (-), MK4.1 (-), MK5.1 (-), MK6.1 (-), R3.2, R6.2, R9.2, R12.2, R15.2, R18.2, U1.2 (-), U1.4 (GND), U2.2 (-), U2.4 (GND), U3.2 (-), U3.4 (GND), U4.2 (-), U4.4 (GND), U5.2 (-), U5.4 (GND), U6.2 (-), U6.4 (GND)
unnamed: C2.1, C5.1, U1.5
unnamed: C2.2, R5.1
unnamed: C3.1, U1.1 (GAIN)
unnamed: C3.2, U1.8 (GAIN)
unnamed: C5.2, R3.1
unnamed: C8.1, U2.1 (GAIN)
unnamed: C8.2, U2.8 (GAIN)
unnamed: C9.2, R6.1
unnamed: C9.1, C10.1, U2.5
unnamed: C10.2, R8.1
unnamed: C13.1, U3.1 (GAIN)
unnamed: C13.2, U3.8 (GAIN)
unnamed: C14.1, C15.1, U3.5
unnamed: C14.2, R9.1
unnamed: C15.2, R2.1
unnamed: C18.1, U4.1 (GAIN)
unnamed: C18.2, U4.8 (GAIN)
unnamed: C19.1, C20.1, U4.5
unnamed: C19.2, R12.1
unnamed: C20.2, R11.1
unnamed: C23.1, U5.1 (GAIN)
unnamed: C23.2, U5.8 (GAIN)
unnamed: C24.1, C25.1, U5.5
unnamed: C24.2, R15.1
unnamed: C25.2, R17.1
unnamed: C28.1, U6.1 (GAIN)
unnamed: C28.2, U6.8 (GAIN)
unnamed: C29.1, C30.1, U6.5
unnamed: C29.2, R18.1
unnamed: C30.2, R14.1
unnamed: C1.1, MK1.2 (+), R1.2
unnamed: C6.1, MK2.2 (+), R4.2
unnamed: C11.1, MK3.2 (+), R7.2
unnamed: C16.1, MK4.2 (+), R10.2
unnamed: C21.1, MK5.2 (+), R13.2
unnamed: C26.1, MK6.2 (+), R16.2
unnamed: C1.2, U1.3 (+)
unnamed: C4.1, U1.7 (BYPASS)
unnamed: C6.2, U2.3 (+)
unnamed: C7.1, U2.7 (BYPASS)
unnamed: C11.2, U3.3 (+)
unnamed: C12.1, U3.7 (BYPASS)
unnamed: C16.2, U4.3 (+)
unnamed: C17.1, U4.7 (BYPASS)
unnamed: C21.2, U5.3 (+)
unnamed: C22.1, U5.7 (BYPASS)
unnamed: C26.2, U6.3 (+)
unnamed: C27.1, U6.7 (BYPASS)

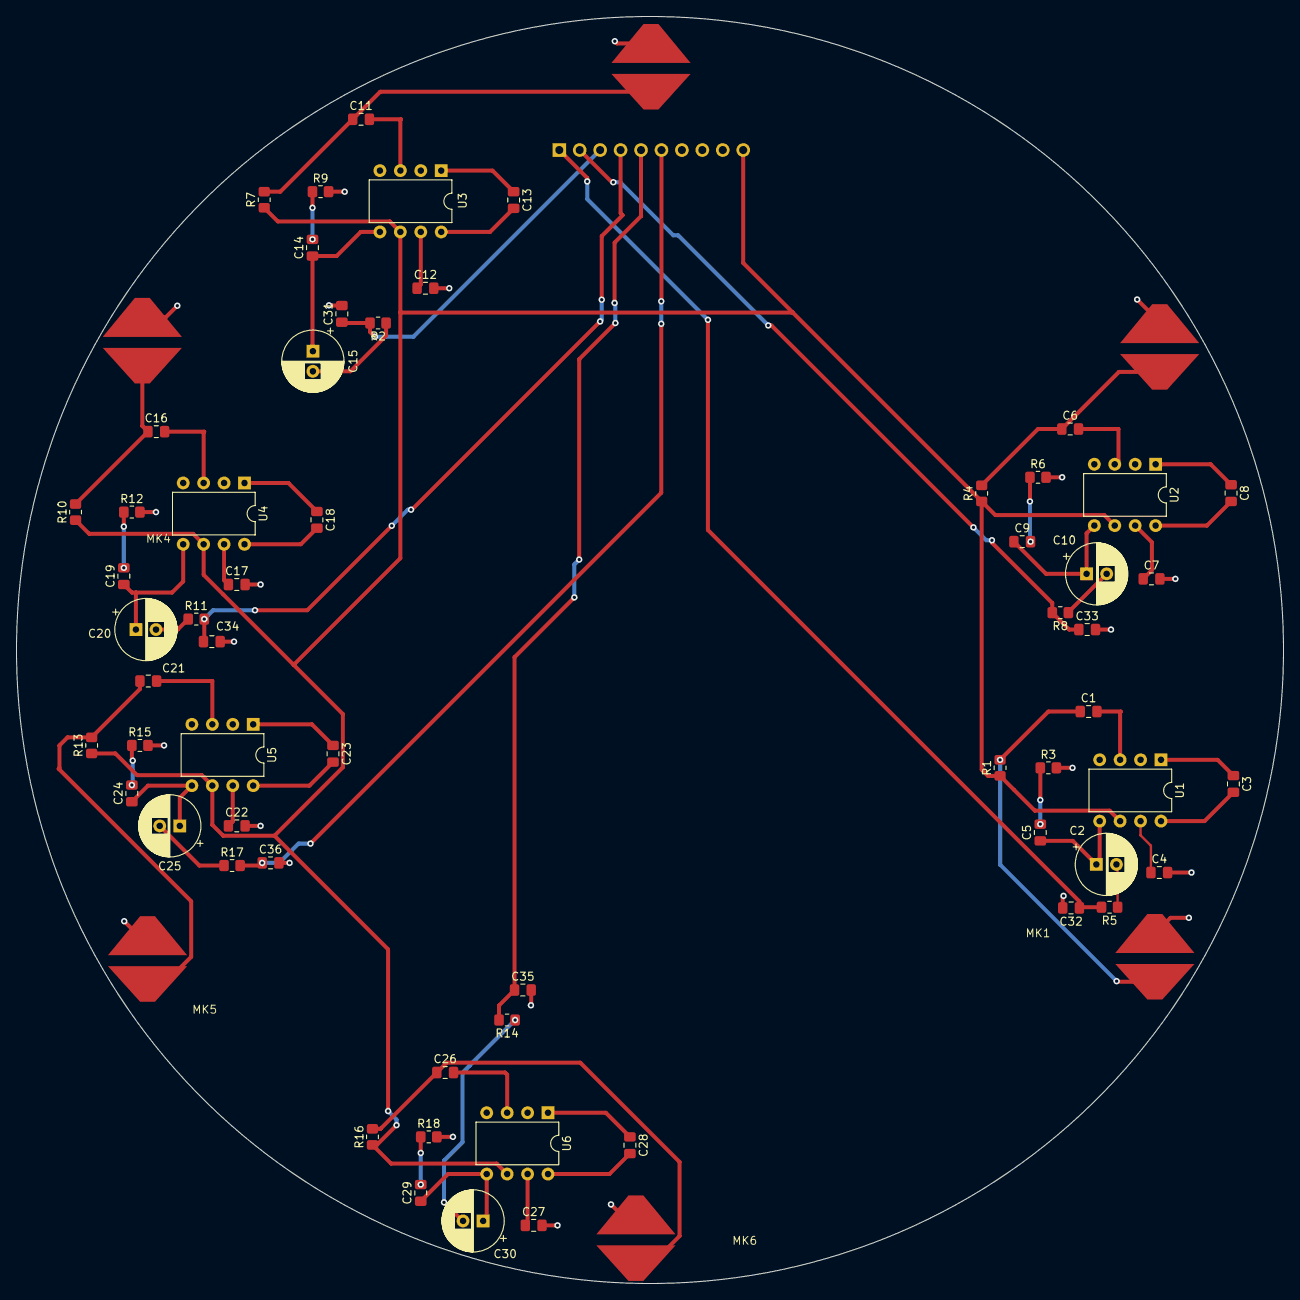
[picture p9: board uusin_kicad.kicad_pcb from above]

Board: 2 copper layers, 157.5 x 157.5 mm, 67 parts (1 on the bottom side), 56 nets.

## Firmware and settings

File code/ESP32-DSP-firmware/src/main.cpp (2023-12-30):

#include <Arduino.h>
#include <WiFi.h>

#include "freertos/FreeRTOS.h"
#include "freertos/task.h"
#include "freertos/semphr.h"
#include "esp_timer.h"

#include "serialstreambuf.hpp"
#include "AD5689.h"
#include "buffer.h"
#include "playbackQueue.h"
#include "ADS8688.h"
#include "taskmanager.hpp"

// Buffer characteristics
static const int buffer_size = 10000;
static const int numberOfADCChannels = 1;

// ADC controll object.
ADS8688 ADC(numberOfADCChannels);

// DAC controll object.
AD5689 DAC;

// Use double buffering. one for signal reading and second for signal processing.
Buffer adc_read_buffer(numberOfADCChannels, buffer_size); // data is read from adc to this buffer.
Buffer dsp_buffer(numberOfADCChannels, buffer_size);      // Data is processed in this buffer.

// process semaphores
SemaphoreHandle_t bufferFilledSemaphore = NULL; // Read buffer has been filled
SemaphoreHandle_t bufferCopiedSemaphore = NULL; // Read buffer has been copied

void fillADCReadBuffer(Buffer &buffer){
  ADC.fillReadBuffer(buffer);
}

float benchmark_adc(Buffer &buffer){
  // Measure ADC sample rate.
  unsigned long long start_time, end_time;
  start_time = micros();
  ADC.fillReadBuffer(buffer);
  end_time = micros();
  unsigned long elapsedTime = end_time - start_time;
  float sample_rate = (float) buffer.getYDim() / (elapsedTime / 1000000.0);  // samples per second
  return sample_rate;
}

void log_data_to_serial(float data){
  Serial.printf("%f\n",data);
}

void core_1_task(void * params) {
  while (true){
    // Wait until core 0 signals that the read buffer has been copied and can be filled again safely.
    xSemaphoreTake(bufferCopiedSemaphore, portMAX_DELAY);
    // Fill read buffer
    fillADCReadBuffer(adc_read_buffer);
    // Signal to core 0 that read buffer is full.
    xSemaphoreGive(bufferFilledSemaphore);
  }
}

void setup() {
  // Initalize ads8688
  ADC.setChannelSPD(0B00000001); // Channel selection (0B00111111: channels 0 to 5 are active )
  ADC.setGlobalRange(VREF);      // Set adc voltage refernce flag
  ADC.autoRst();                 // Set ADC to auto reset mode

  Serial.begin(250000);
  // Turning off the WiFi
  WiFi.mode(WIFI_OFF);
  bufferFilledSemaphore = xSemaphoreCreateBinary();
  bufferCopiedSemaphore = xSemaphoreCreateBinary();
  xSemaphoreGive(bufferCopiedSemaphore);
  //Set up DAC
  DAC.reset();
  // Initialize TaskManager and add tasks
  TaskManager taskManager;
  taskManager.addTask(TaskConfig(core_1_task, "Fill ADC read buffer", 10024, NULL, 1, 1), 0); // Task for core 1 with priortity 0 (Highest priority)
  taskManager.startTask();
  
}

void loop() {

  SerialStreambuf espout; // IO stream for serial port
  std::ostream serialOut(&espout);

  float sample_rate_kHz;
  sample_rate_kHz =  benchmark_adc(adc_read_buffer) / 1e3;

  while(true){ 

    if (xSemaphoreTake(bufferFilledSemaphore, portMAX_DELAY) == pdTRUE) {
      // Copy data from adc_read_buffer to dsp_buffer
      dsp_buffer.copyBuffer(adc_read_buffer);
      // Tell core 1 buffer has been copied.
      xSemaphoreGive(bufferCopiedSemaphore);
    }

    serialOut << "BEGIN\n";
    serialOut << "Sample rate: " << sample_rate_kHz << " kHz\n\n";

    
    for (int i = 0; i < dsp_buffer.getYDim(); i++){
      // Read data from dsp_buffer
      serialOut << dsp_buffer.getValue(0, i) << "," << "\n"; // Write data to serial port
    }
    serialOut << "END\n";
  }
}

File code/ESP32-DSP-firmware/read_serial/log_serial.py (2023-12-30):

import serial as srl
import sys

class SerialLogger:

    def __init__(self, PORT, BAUD_RATE, output_file) -> None:
        self.port = PORT
        self.baud_rate = BAUD_RATE
        self.out_file = output_file

    def read_and_save(self):
        with srl.Serial(self.port, self.baud_rate, timeout=1) as ser:
            with open(self.out_file, "w") as out_f:

                # Wait for the line to contain "START"
                while True:
                    try:
                        line = ser.readline().decode('utf-8').strip()
                        if line == "BEGIN":
                            out_f.write(f"{line}\n")
                            break

                    except Exception as e:
                        print(f"Error: {e}")
                        break


                while True:
                    try:
                        line = ser.readline().decode('utf-8').strip()
                        out_f.write(f"{line}\n")
                        if line == "END":
                            break

                    except Exception as e:
                        print(f"Error: {e}")
                        break

        print(f"Data saved to {self.out_file}")
        return



def usage():
    print(
        f"Usage:"
        f"python3 log_serial.py <port> <baud rate>"
        f"\n----------------------------------------------\n"
    )
    return


def main(args):

    if ('-h' in args) or len(args) <= 2:
        usage()
        return
    
    port = sys.argv[1]
    baud = int(sys.argv[2])

    logger = SerialLogger(PORT=port, BAUD_RATE=baud, output_file="serial_out.txt")

    print(f"Reading from serial port {port} at baud {baud}")
    logger.read_and_save()

    return

if __name__ == "__main__":
    main(sys.argv)

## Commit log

2023-09-19 Added pcb proto
    [ESP-32-DSP_board.kicad_pcb, ESP-32-DSP_board.kicad_sch]
2023-09-19 Separated GND and GNDA
    [ESP-32-DSP_board.kicad_pcb, ESP-32-DSP_board.kicad_sch]
2023-09-20 Updated ADC configutation
    [ESP-32-DSP_board.kicad_pcb, ESP-32-DSP_board.kicad_sch]
2023-09-20 Arduino framework test code for MCP3008
2023-09-20 Added hardware timer to control ADC sample rate
2023-09-21 Latest pcb version
    [ESP-32-DSP_board.kicad_sch]
2023-09-26 Organised code and added hardware timer to ADS8688 class =)
2023-09-27 Added muti-channel support to ADC and created dedicated buffer class
2023-10-27 ESP32-S3 version of dsp board with SD-card and DAC added
    [ESP-32-DSP_board.kicad_pcb, ESP-32-DSP_board.kicad_sch, MCU.kicad_sch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]
2023-10-29 First working version of S3 dsp board
    [ESP-32-DSP_board.kicad_pcb, ESP-32-DSP_board.kicad_sch]
2023-11-01 vihdoin äijät
    [Bom_excel.xlsx, uusin_kicad.kicad_pcb, uusin_kicad.kicad_sch]
2023-11-01 ESP32-S3 DSP updates
    [BOM.xlsx, Book4.xlsx, ESP-32-DSP_board.kicad_pcb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]
2023-11-02 Fixed mistake in S3 dsp
    [ESP-32-DSP_board.kicad_pcb, ESP-32-DSP_board.kicad_sch]
2023-11-02 ESP32-S3 DSP board
    [BOM.xlsx, Book4.xlsx, Components.xlsx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]
2023-11-04 Componets list for S3 dsp board
    [Components.xlsx]
2023-11-04 Added all component order links
    [Components.xlsx]
2023-11-04 Added local pcb modifications
    [ESP-32-DSP_board.kicad_pcb, ESP-32-DSP_board.kicad_sch]
2023-11-04 Removed KiCad autosave files
2023-11-04 Added board production files
    [bom.csv, designators.csv, positions.csv]
2023-11-04 ESP32 DSP board Gerber files
2023-11-04 Added price to components lists
    [Bom_excel.xlsx, Components.xlsx]
2023-11-04 Added production files for microphone circuit
    [bom.csv, designators.csv, positions.csv]
2023-11-07 Digikey and Mouser order forms
    [Digi-Key_Tilaus_RyhmaX.xls, Mouser_Tilaus_Ryhma15.xls, Mouser_Tilaus_RyhmaX.xls]
2023-11-13 Removed order forms from git
    [Digi-Key_Tilaus_RyhmaX.xls, Mouser_Tilaus_Ryhma15.xls, Mouser_Tilaus_RyhmaX.xls]
2023-11-13 cleanded pcb directory
    [Bom_excel.xlsx, Components.xlsx, ESP-32-DSP_Components.xlsx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]
